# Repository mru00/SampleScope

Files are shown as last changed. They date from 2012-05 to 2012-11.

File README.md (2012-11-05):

SampleScope
===========

A cheap, simple, and fun-to-build diy USB oscilloscope

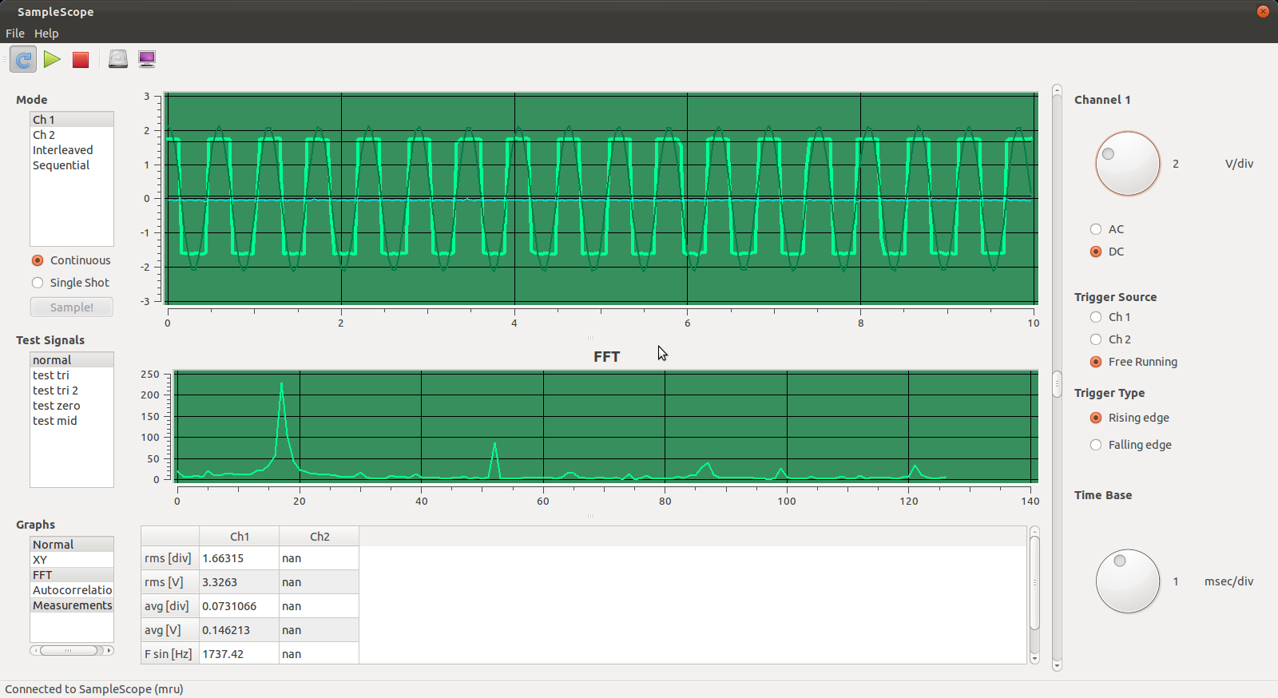
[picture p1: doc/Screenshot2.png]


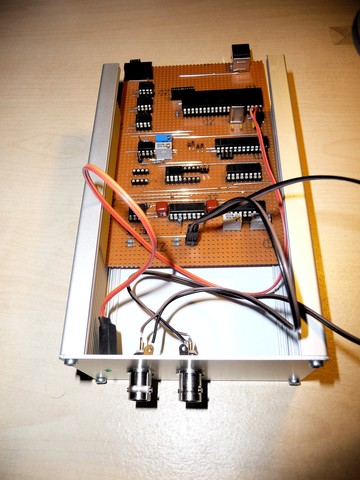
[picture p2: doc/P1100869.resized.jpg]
PCB


Schematics based on http://jonw0224.tripod.com/ppmscope.html

* USB oscilloscope
* two channels
* almost all parts can be sampled directly from the manufacturer
* almost no parts needed anyhow, some capacitors and resistors
* pcb is really simple an can be done on perfboard
* input range +- 12V
* bandwidth about 200kHz, 1MSPS
* 1024 samples 

Hardware
--------

* PIC18F4455
* USB 2.0 Full Speed HID device
* simple analog part
 * input limiting & buffering
 * optional DC removal
 * programmable gain amplifier (0.05, 0.1, 0.2, 0.5, 1, 2, 5, 10 V/div)
 * level shifter
 * ADC
 * no anti aliasing filter
* trigger system
 * can trigger on both channel 1, channel 2, or free running
 * can trigger on rising or falling edge
* time bases 'fastest' (~17u), 100u, 300u, 1m, 3m, 10m, 30m, 100m sec/div
* input selection
 * sample single channel, two channel interleaved or two channel sequential
* uses dc-dc converter (xp power IQ0515) to supply analog circuitry
* everything is powered from USB - no external supply required

* IC List
 * all parts can be sampled, at least as a student.
 * MAX114 as ADC
 * MAX532 as DAC: programmable gain amplifier and trigger voltage generation
 * MAX942 as trigger comparator
 * MAX4622 as AC/DC selector
 * MAX6225, MAX6241, MAX6250 as voltage references
 * TLE2082 as Op Amp
 * PIC18F4455 as brain
 
* PCB
 * as simple as it gets
 * analog parts are simple to wire
 * digital connections are "flying wires", verowire

Firmware
--------

Very simple firmware based on the Microchip Application Library USB example, 
most parts written in C, sampling routines written in ASM.

Frontend
--------

PC software written in C++ / Qt. OS independence by using libHIDAPI.
* Hardware emulation
* Plots
 * Normal
 * XY plot
 * FFT
 * autocorrelation
* Measurements
 * frequency
 * RMS and average voltage
* software emulation mode
 * emulates hardware, allows testing without the actual device

* development
 * uses HIDAPI https://github.com/signal11/hidapi
 * libqt4
 * libfftw3
 * libqwt6
 * libusb-1.0

To do
-----

* build better PGA (the current one is the main bottleneck in bandwidth)
* put more effort into PCB layout
 * i fixed some errors "on-line" without rerouting the pcb
* find cheaper DC-DC converter
* put some effort into graphical frontend
 * more measurements
 * more switches and customization
 * clean calibration ui, calibration wizards
* cleanup code a little bit, get build environment better (link with HIDAPI)
* platform independence (HIDAPI, libusb)
* anti aliasing filter (!!!)

Probably I won't do any of those items. ;)

License
-------
    SampleScope
    Copyright (C) 2012 mru

    This program is free software: you can redistribute it and/or modify
    it under the terms of the GNU General Public License as published by
    the Free Software Foundation, either version 3 of the License, or
    (at your option) any later version.

    This program is distributed in the hope that it will be useful,
    but WITHOUT ANY WARRANTY; without even the implied warranty of
    MERCHANTABILITY or FITNESS FOR A PARTICULAR PURPOSE.  See the
    GNU General Public License for more details.

    You should have received a copy of the GNU General Public License
    along with this program.  If not, see <http://www.gnu.org/licenses/>.

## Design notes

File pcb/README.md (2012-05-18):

pcb
===

contains the schematics & pcb layout.

see /doc/schematics.pdf and /doc/pcb.pdf for rendered versions, 
or check out kicad:

kicad schematic entry & pcb layout software.
http://iut-tice.ujf-grenoble.fr/kicad/

NB: the schematics and pcb layout are quite messy - i did not
draw them for the "end user" but rather as guide for me.

nevertheless, with some care, the device should be buildable.

analog
------

all analog paths (except some quick-fixes on my actual hardware) are routed
directly to fit on a perfboard. top and bottom layer are used, while
the top layer only has vertical connections.

digital
-------

all digital connections are simple point-to-point connections
with insolated wire (cf. http://en.wikipedia.org/wiki/Wiring_pencil)
_.

issues
------

* Analog bandwith is mostly limited by the PGA (MAX532) -> find a better solution
* Inputs are wired terribly, huge crosstalk if one channel is left unconnected -> change layout

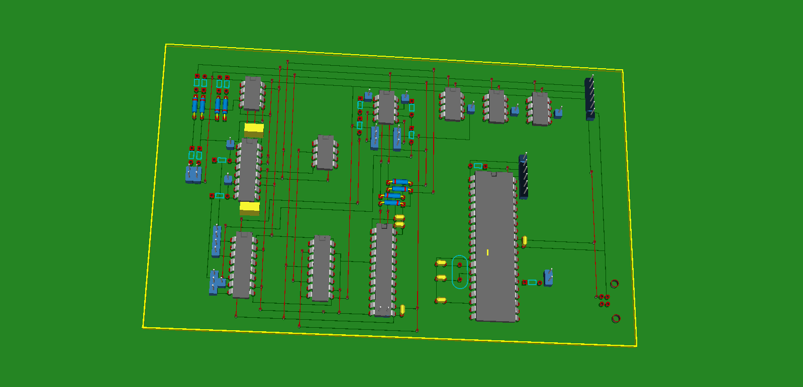
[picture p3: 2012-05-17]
doc/pcb_3d.png

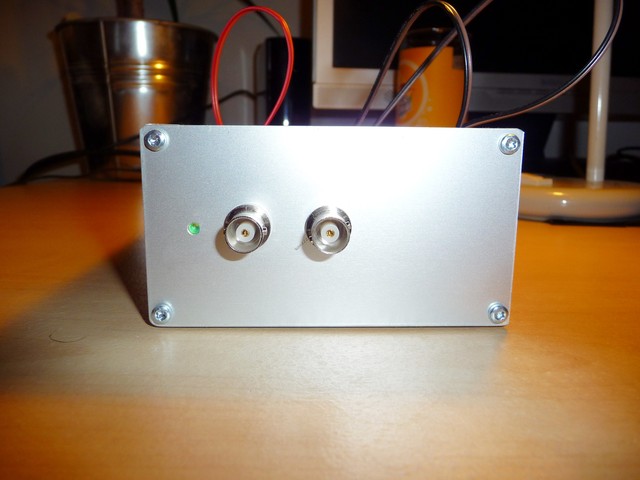
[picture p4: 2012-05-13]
doc/P1100871.resized.jpeg

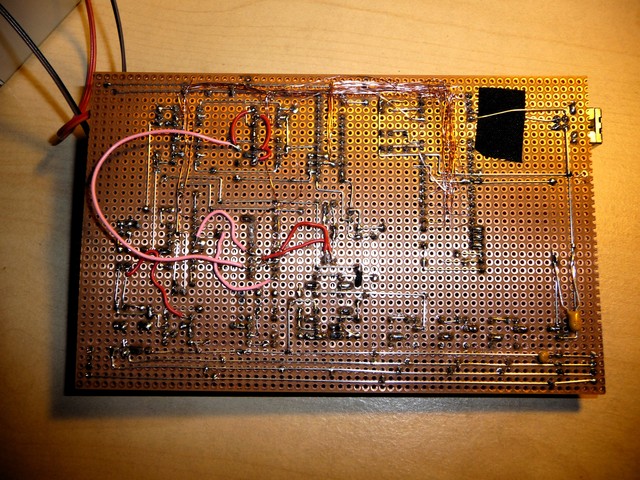
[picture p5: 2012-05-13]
doc/P1100872.resized.jpeg

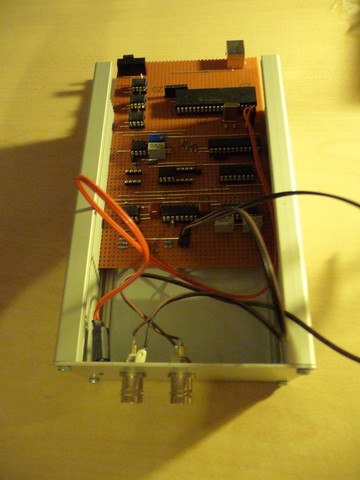
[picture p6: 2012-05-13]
doc/P1100868.resized.jpg

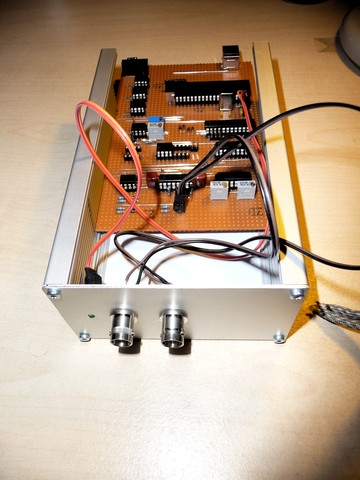
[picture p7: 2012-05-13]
doc/P1100870.resized.jpeg

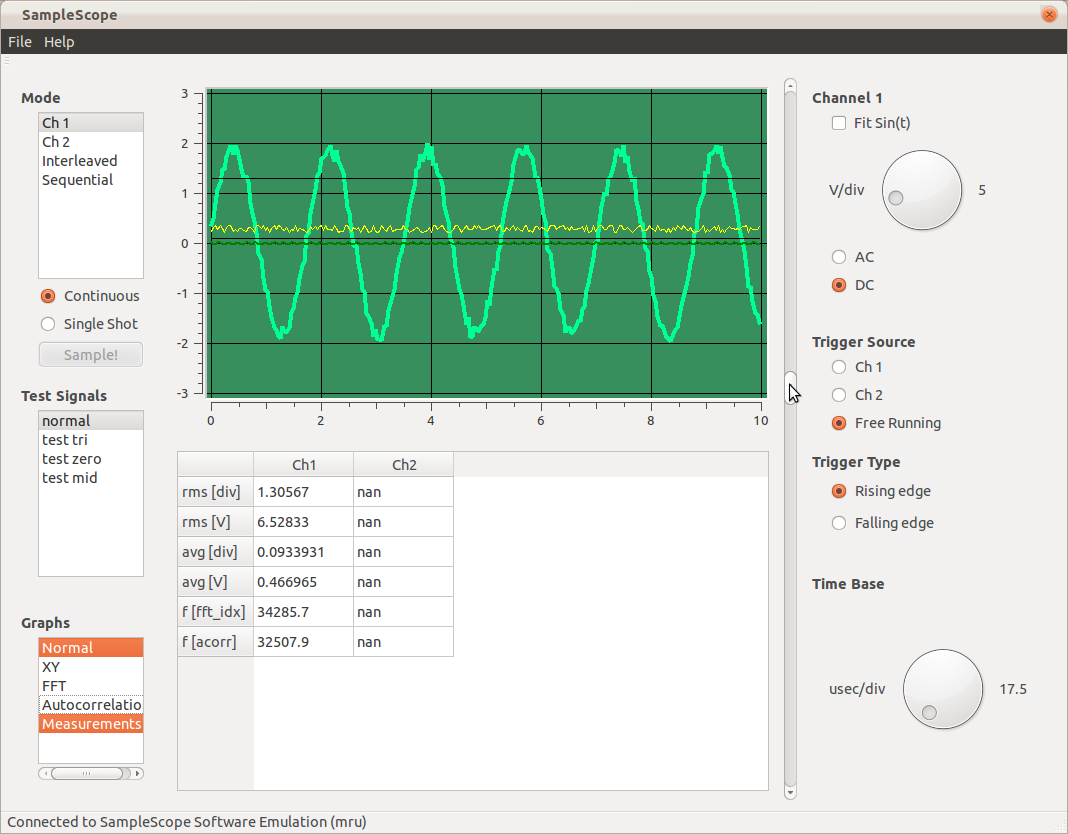
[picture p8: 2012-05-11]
doc/Screenshot1.png

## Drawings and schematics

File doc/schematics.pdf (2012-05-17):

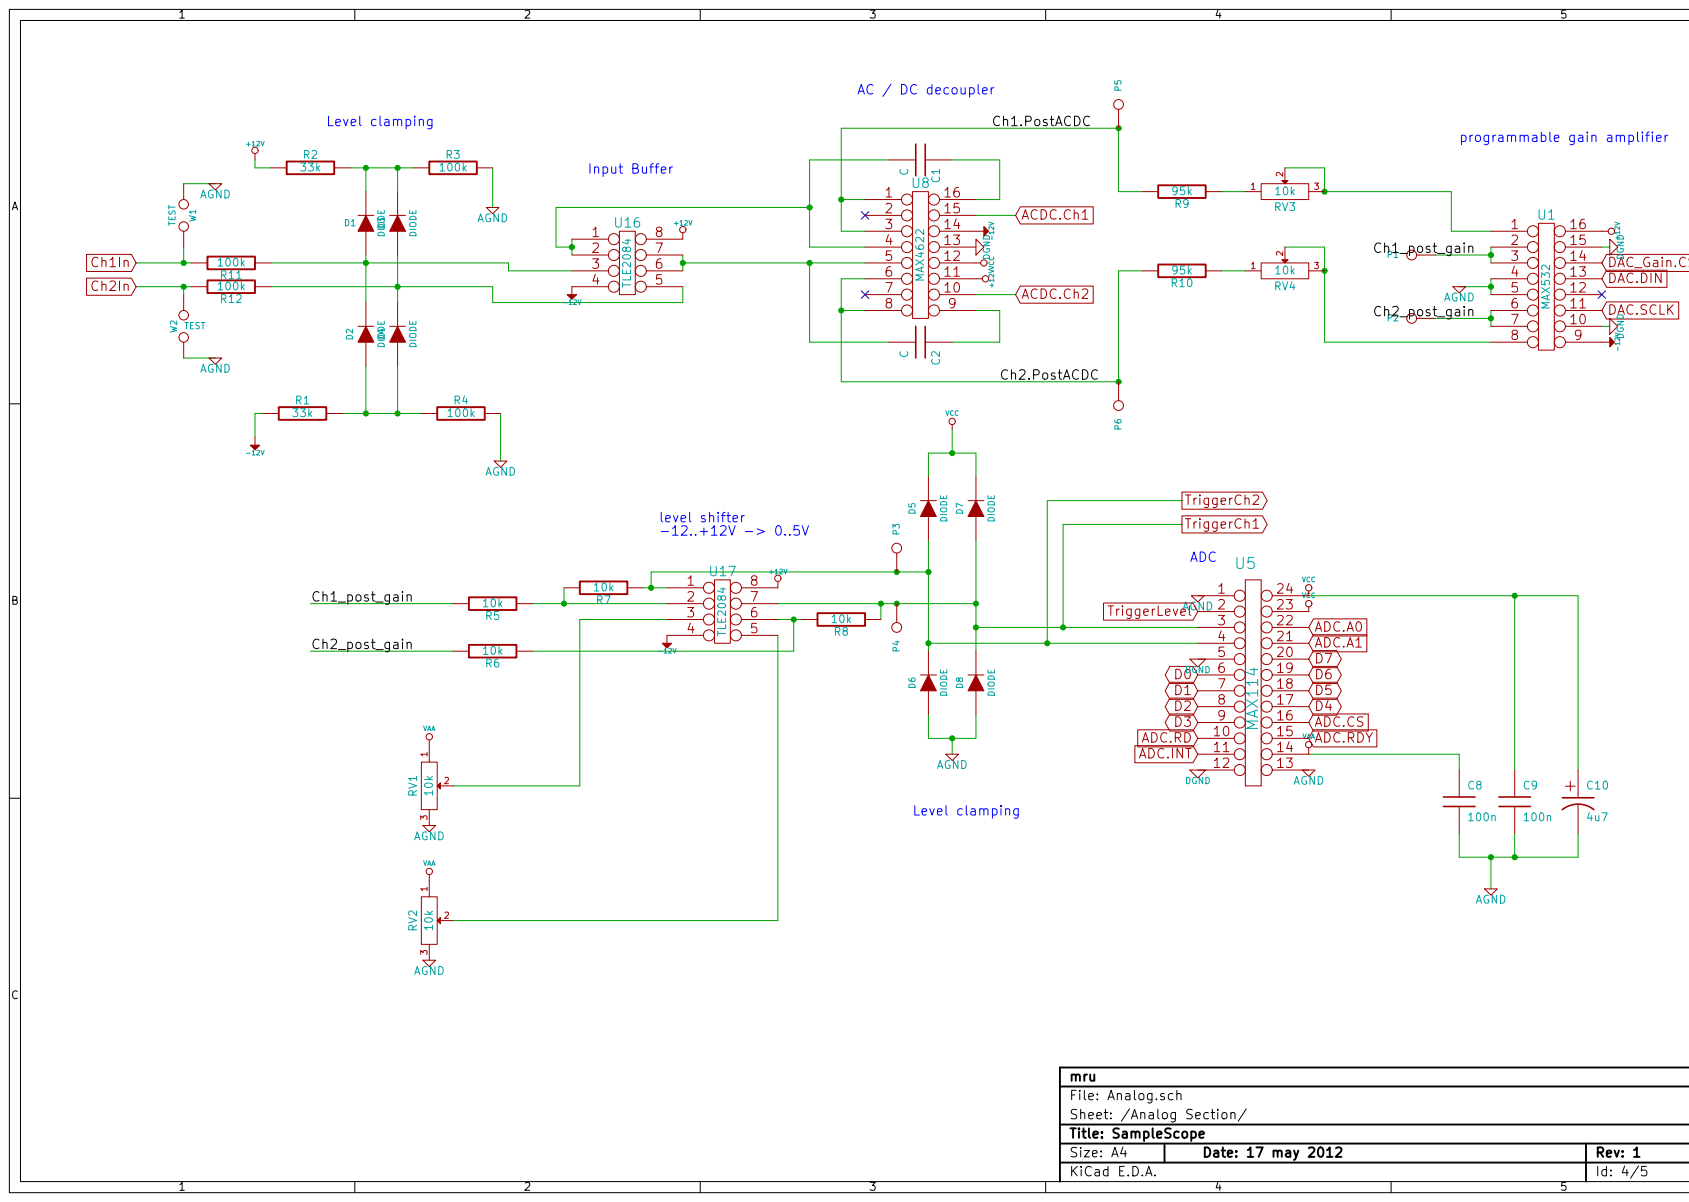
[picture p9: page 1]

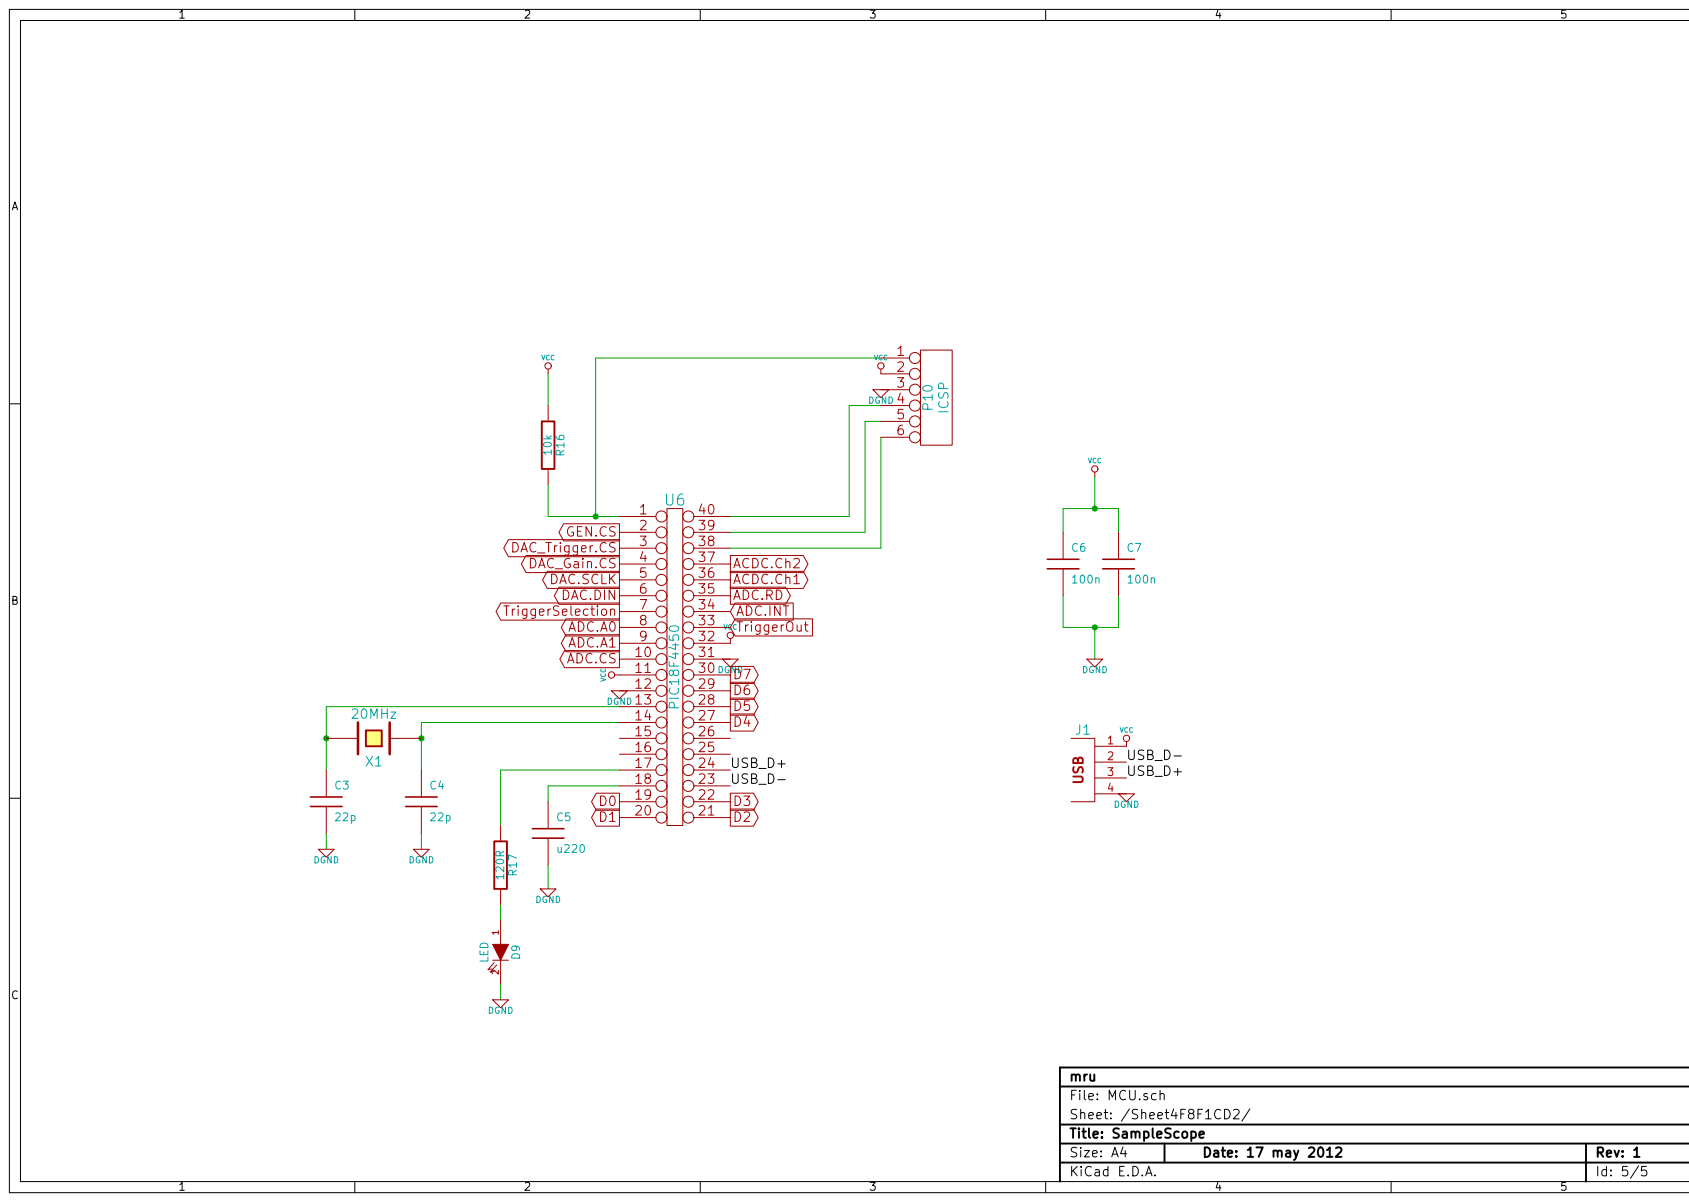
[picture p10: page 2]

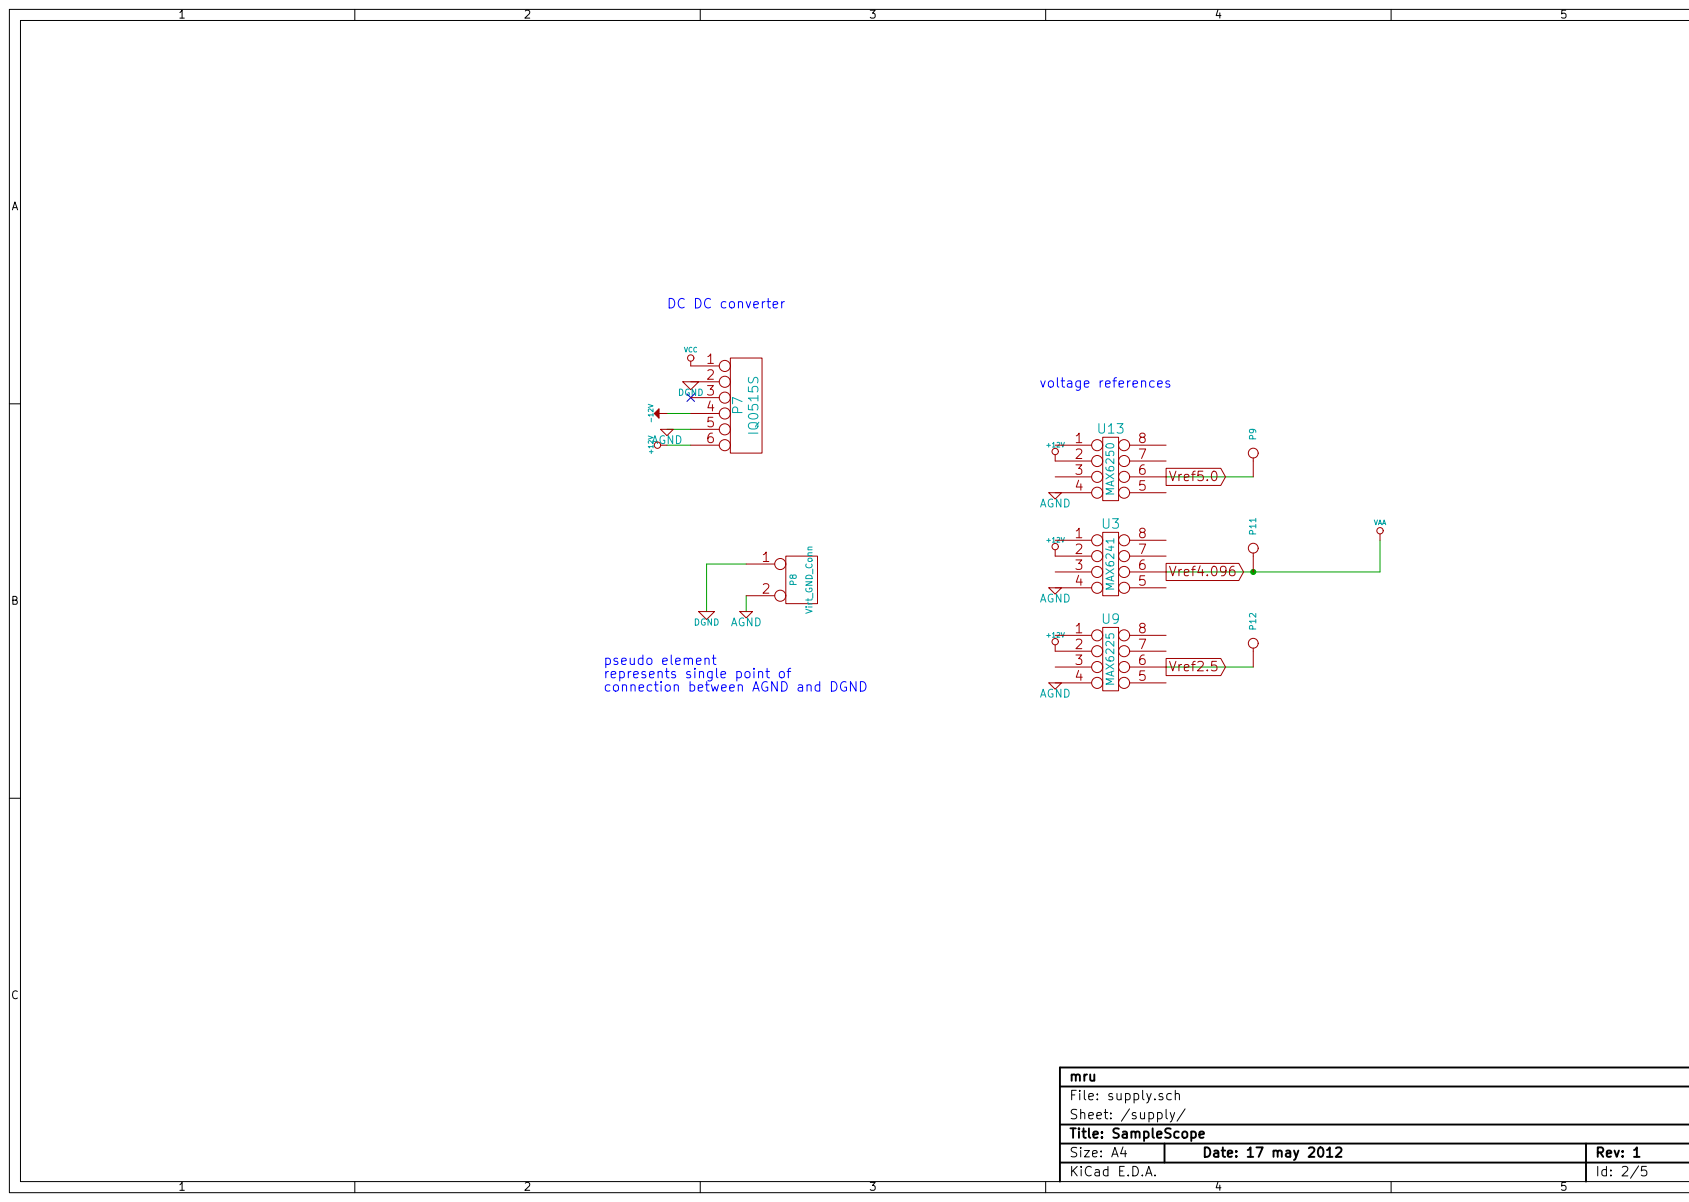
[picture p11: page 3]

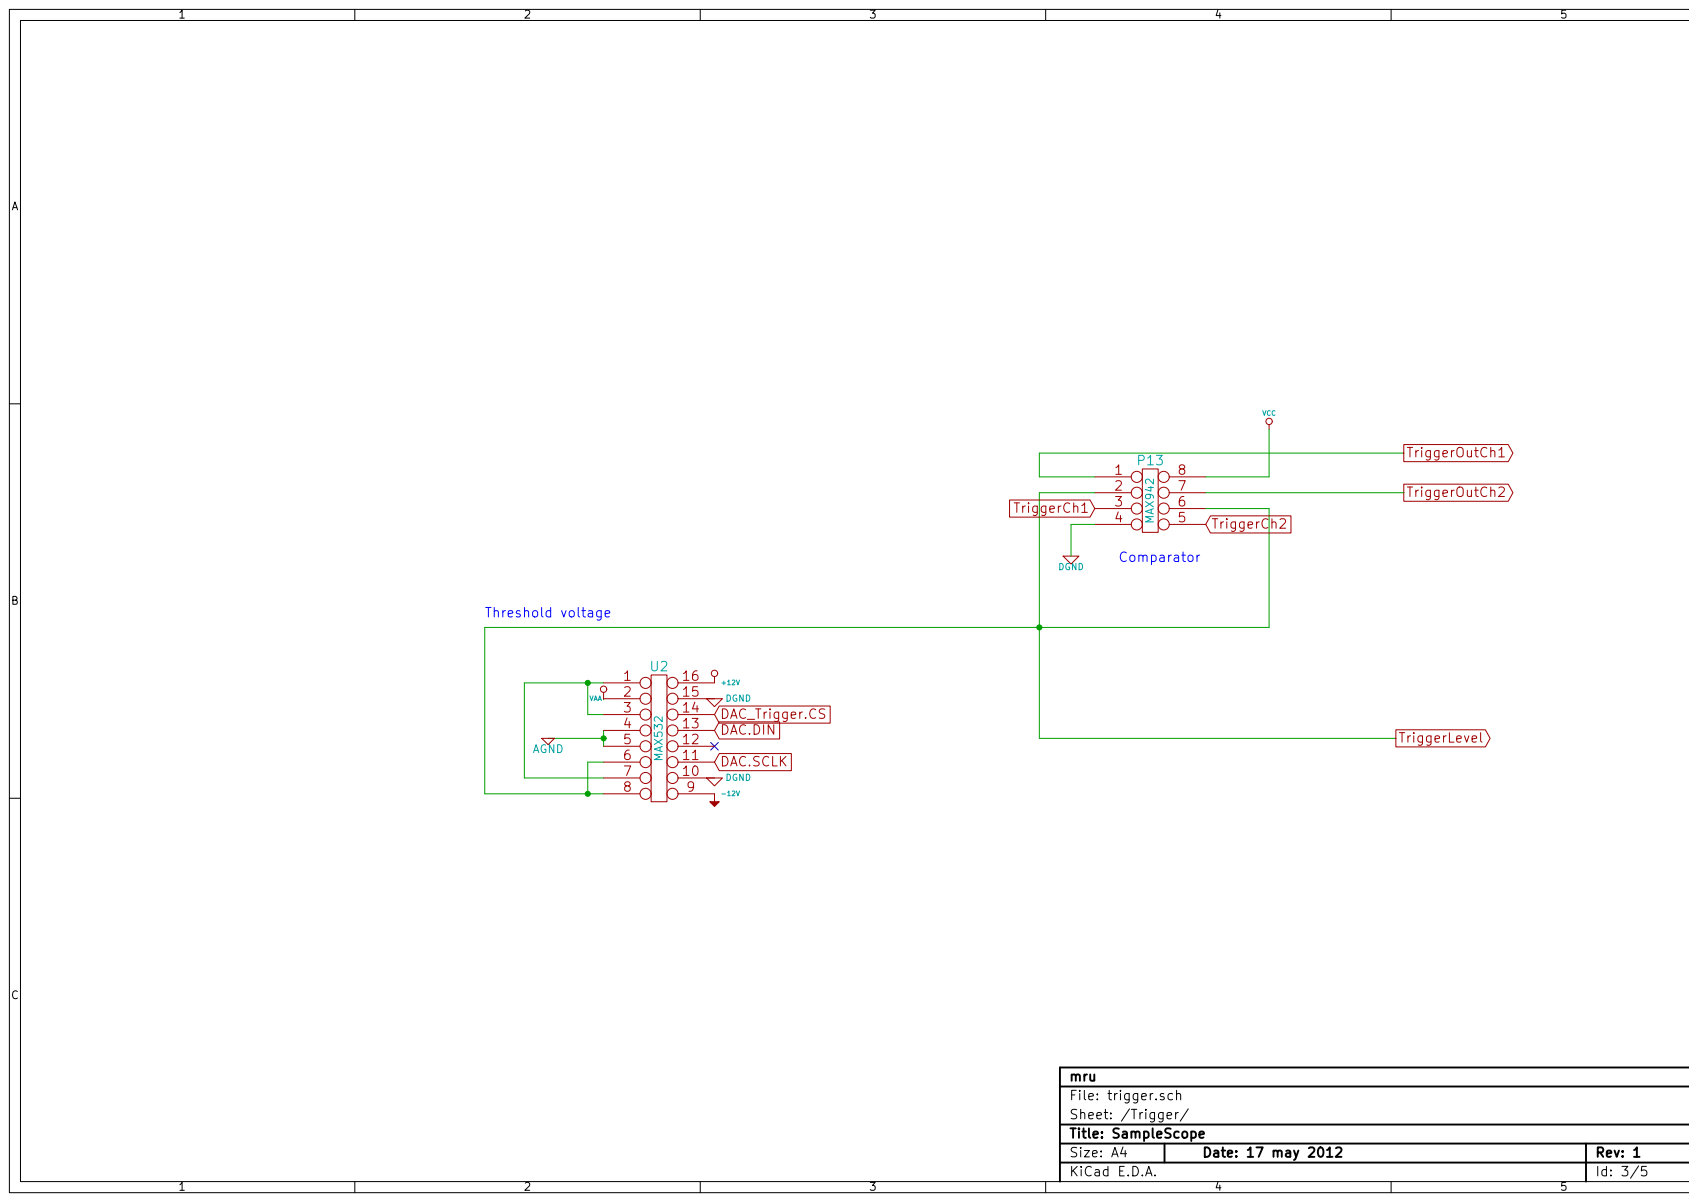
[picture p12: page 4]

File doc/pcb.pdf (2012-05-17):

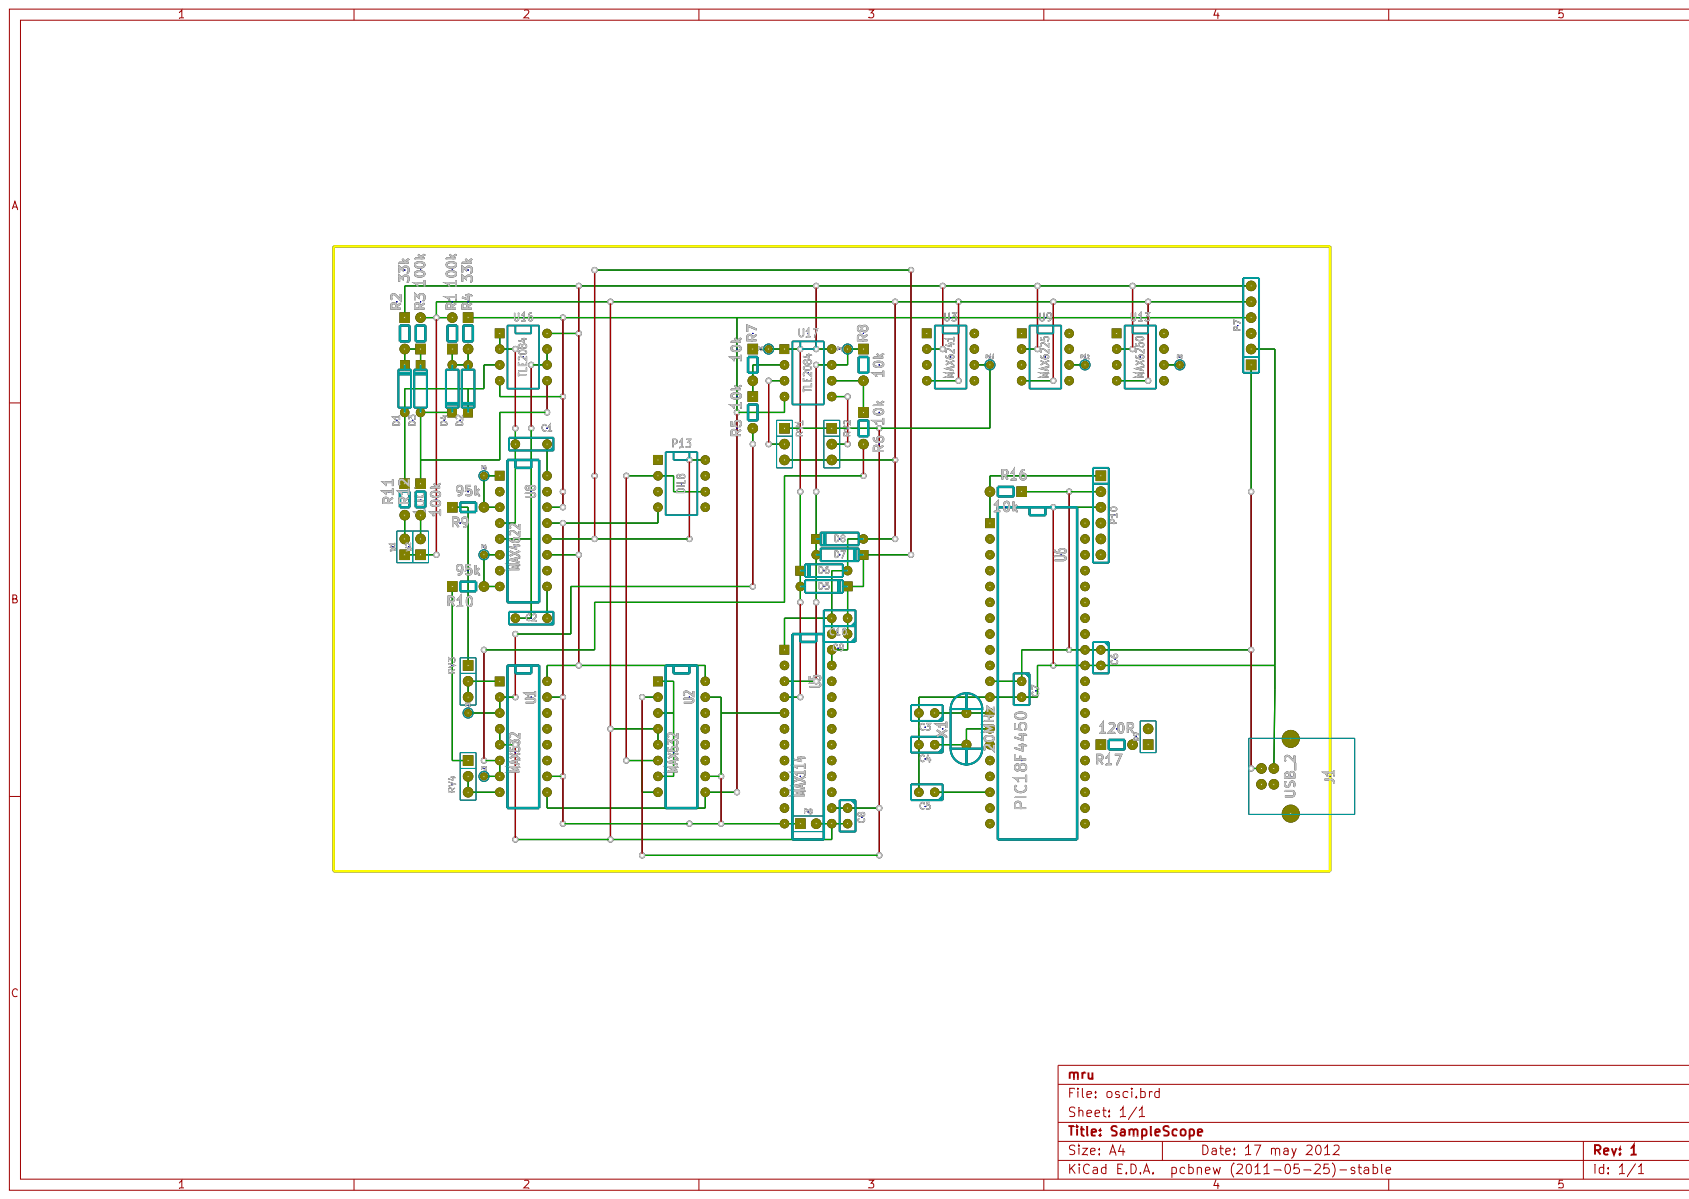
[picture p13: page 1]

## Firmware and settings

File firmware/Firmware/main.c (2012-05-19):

/********************************************************************
 FileName:     main.c
 Dependencies: See INCLUDES section
 Processor:		PIC18, PIC24, and PIC32 USB Microcontrollers
 Hardware:		This demo is natively intended to be used on Microchip USB demo
                                boards supported by the MCHPFSUSB stack.  See release notes for
                                support matrix.  This demo can be modified for use on other hardware
                                platforms.
 Complier:  	Microchip C18 (for PIC18), C30 (for PIC24), C32 (for PIC32)
 Company:		Microchip Technology, Inc.

 Software License Agreement:

 The software supplied herewith by Microchip Technology Incorporated
 (the �Company�) for its PIC� Microcontroller is intended and
 supplied to you, the Company�s customer, for use solely and
 exclusively on Microchip PIC Microcontroller products. The
 software is owned by the Company and/or its supplier, and is
 protected under applicable copyright laws. All rights are reserved.
 Any use in violation of the foregoing restrictions may subject the
 user to criminal sanctions under applicable laws, as well as to
 civil liability for the breach of the terms and conditions of this
 license.

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
 ********************************************************************
 File Description:

 Change History:
  Rev   Description
  ----  -----------------------------------------
  1.0   Initial release
  2.1   Updated for simplicity and to use common
                     coding style
  2.7b  Improvements to USBCBSendResume(), to make it easier to use.
 ********************************************************************/


/** INCLUDES *******************************************************/
#include "./USB/usb.h"
#include "./HardwareProfile.h"
#include "./USB/usb_function_hid.h"
#include <timers.h>
#include <compare.h>


#include "config_bits.h"


/** VARIABLES ******************************************************/
#pragma udata USB_VARIABLES=0x480
unsigned char ReceivedData[64];
unsigned char ToSendDataBuffer[64];

#pragma idata

USB_HANDLE USBOutHandle = 0;
USB_HANDLE USBInHandle = 0;

/** PRIVATE PROTOTYPES *********************************************/
static void InitializeSystem(void);
extern void ProcessIO(void);
extern void UserInit(void);

//void USBCBSendResume(void);
static void BlinkUSBStatus(void);
extern void resetState(void);

/** DECLARATIONS ***************************************************/
#pragma code

/********************************************************************
 * Function:        void main(void)
 *
 * PreCondition:    None
 *
 * Input:           None
 *
 * Output:          None
 *
 * Side Effects:    None
 *
 * Overview:        Main program entry point.
 *
 * Note:            None
 *******************************************************************/
void main(void) {
    InitializeSystem();

#if defined(USB_INTERRUPT)
    USBDeviceAttach();
#endif

    while (1) {
#if defined(USB_POLLING)
        // Check bus status and service USB interrupts.
        USBDeviceTasks(); // Interrupt or polling method.  If using polling, must call
        // this function periodically.  This function will take care
        // of processing and responding to SETUP transactions
        // (such as during the enumeration process when you first
        // plug in).  USB hosts require that USB devices should accept
        // and process SETUP packets in a timely fashion.  Therefore,
        // when using polling, this function should be called
        // regularly (such as once every 1.8ms or faster** [see
        // inline code comments in usb_device.c for explanation when
        // "or faster" applies])  In most cases, the USBDeviceTasks()
        // function does not take very long to execute (ex: <100
        // instruction cycles) before it returns.
#endif


        // Application-specific tasks.
        // Application related code may be added here, or in the ProcessIO() function.
        ProcessIO();
    }//end while
}//end main

/********************************************************************
 * Function:        static void InitializeSystem(void)
 *
 * Overview:        InitializeSystem is a centralize initialization
 *                  routine. All required USB initialization routines
 *                  are called from here.
 *
 *                  User application initialization routine should
 *                  also be called from here.                  
 *
 * Note:            None
 *******************************************************************/
static void InitializeSystem(void) {
    ADCON1 |= 0x0F; // Default all pins to digital

#if defined(PIC18F87J50_PIM) || defined(PIC18F46J50_PIM) || defined(PIC18F_STARTER_KIT_1) || defined(PIC18F47J53_PIM)
    //On the PIC18F87J50 Family of USB microcontrollers, the PLL will not power up and be enabled
    //by default, even if a PLL enabled oscillator configuration is selected (such as HS+PLL).
    //This allows the device to power up at a lower initial operating frequency, which can be
    //advantageous when powered from a source which is not gauranteed to be adequate for 48MHz
    //operation.  On these devices, user firmware needs to manually set the OSCTUNE<PLLEN> bit to
    //power up the PLL.
    {
        unsigned int pll_startup_counter = 600;
        OSCTUNEbits.PLLEN = 1; //Enable the PLL and wait 2+ms until the PLL locks before enabling USB module
        while (pll_startup_counter--);
    }
    //Device switches over automatically to PLL output after PLL is locked and ready.
#endif

#if defined(PIC18F87J50_PIM)
    //Configure all I/O pins to use digital input buffers.  The PIC18F87J50 Family devices
    //use the ANCONx registers to control this, which is different from other devices which
    //use the ADCON1 register for this purpose.
    WDTCONbits.ADSHR = 1; // Select alternate SFR location to access ANCONx registers
    ANCON0 = 0xFF; // Default all pins to digital
    ANCON1 = 0xFF; // Default all pins to digital
    WDTCONbits.ADSHR = 0; // Select normal SFR locations
#endif


    //	The USB specifications require that USB peripheral devices must never source
    //	current onto the Vbus pin.  Additionally, USB peripherals should not source
    //	current on D+ or D- when the host/hub is not actively powering the Vbus line.
    //	When designing a self powered (as opposed to bus powered) USB peripheral
    //	device, the firmware should make sure not to turn on the USB module and D+
    //	or D- pull up resistor unless Vbus is actively powered.  Therefore, the
    //	firmware needs some means to detect when Vbus is being powered by the host.
    //	A 5V tolerant I/O pin can be connected to Vbus (through a resistor), and
    // 	can be used to detect when Vbus is high (host actively powering), or low
    //	(host is shut down or otherwise not supplying power).  The USB firmware
    // 	can then periodically poll this I/O pin to know when it is okay to turn on
    //	the USB module/D+/D- pull up resistor.  When designing a purely bus powered
    //	peripheral device, it is not possible to source current on D+ or D- when the
    //	host is not actively providing power on Vbus. Therefore, implementing this
    //	bus sense feature is optional.  This firmware can be made to use this bus
    //	sense feature by making sure "USE_USB_BUS_SENSE_IO" has been defined in the
    //	HardwareProfile.h file.
#if defined(USE_USB_BUS_SENSE_IO)
    tris_usb_bus_sense = INPUT_PIN; // See HardwareProfile.h
#endif

    //	If the host PC sends a GetStatus (device) request, the firmware must respond
    //	and let the host know if the USB peripheral device is currently bus powered
    //	or self powered.  See chapter 9 in the official USB specifications for details
    //	regarding this request.  If the peripheral device is capable of being both
    //	self and bus powered, it should not return a hard coded value for this request.
    //	Instead, firmware should check if it is currently self or bus powered, and
    //	respond accordingly.  If the hardware has been configured like demonstrated
    //	on the PICDEM FS USB Demo Board, an I/O pin can be polled to determine the
    //	currently selected power source.  On the PICDEM FS USB Demo Board, "RA2"
    //	is used for	this purpose.  If using this feature, make sure "USE_SELF_POWER_SENSE_IO"
    //	has been defined in HardwareProfile.h, and that an appropriate I/O pin has been mapped
    //	to it in HardwareProfile.h.
#if defined(USE_SELF_POWER_SENSE_IO)
    tris_self_power = INPUT_PIN; // See HardwareProfile.h
#endif

    UserInit();

    USBDeviceInit(); //usb_device.c.  Initializes USB module SFRs and firmware
    //variables to known states.
}//end InitializeSystem


/********************************************************************
 * Function:        void BlinkUSBStatus(void)
 *
 * PreCondition:    None
 *
 * Input:           None
 *
 * Output:          None
 *
 * Side Effects:    None
 *
 * Overview:        BlinkUSBStatus turns on and off LEDs 
 *                  corresponding to the USB device state.
 *
 * Note:            mLED macros can be found in HardwareProfile.h
 *                  USBDeviceState is declared and updated in
 *                  usb_device.c.
 *******************************************************************/
void BlinkUSBStatus(void) {
    // No need to clear UIRbits.SOFIF to 0 here.
    // Callback caller is already doing that.

    if (USBSuspendControl == 1) {
    } else {
        if (USBDeviceState == DETACHED_STATE) {
        } else if (USBDeviceState == ATTACHED_STATE) {
        } else if (USBDeviceState == POWERED_STATE) {
        } else if (USBDeviceState == DEFAULT_STATE) {
        } else if (USBDeviceState == ADDRESS_STATE) {
        } else if (USBDeviceState == CONFIGURED_STATE) {
        }
    }

}//end BlinkUSBStatus

/*******************************************************************
 * Function:        void USBCBInitEP(void)
 *
 * PreCondition:    None
 *
 * Input:           None
 *
 * Output:          None
 *
 * Side Effects:    None
 *
 * Overview:        This function is called when the device becomes
 *                  initialized, which occurs after the host sends a
 * 					SET_CONFIGURATION (wValue not = 0) request.  This
 *					callback function should initialize the endpoints
 *					for the device's usage according to the current
 *					configuration.
 *
 * Note:            None
 *******************************************************************/
void USBCBInitEP(void) {
    //enable the HID endpoint
    USBEnableEndpoint(HID_EP, USB_IN_ENABLED | USB_OUT_ENABLED | USB_HANDSHAKE_ENABLED | USB_DISALLOW_SETUP);
    //Re-arm the OUT endpoint for the next packet
    USBOutHandle = HIDRxPacket(HID_EP, (BYTE*) & ReceivedData, 64);
    resetState();
}

/*******************************************************************
 * Function:        void USBCBErrorHandler(void)
 *
 * PreCondition:    None
 *
 * Input:           None
 *
 * Output:          None
 *
 * Side Effects:    None
 *
 * Overview:        The purpose of this callback is mainly for
 *                  debugging during development. Check UEIR to see
 *                  which error causes the interrupt.
 *
 * Note:            None
 *******************************************************************/
void USBCBErrorHandler(void) {
    // No need to clear UEIR to 0 here.
    // Callback caller is already doing that.

    // Typically, user firmware does not need to do anything special
    // if a USB error occurs.  For example, if the host sends an OUT
    // packet to your device, but the packet gets corrupted (ex:
    // because of a bad connection, or the user unplugs the
    // USB cable during the transmission) this will typically set
    // one or more USB error interrupt flags.  Nothing specific
    // needs to be done however, since the SIE will automatically
    // send a "NAK" packet to the host.  In response to this, the
    // host will normally retry to send the packet again, and no
    // data loss occurs.  The system will typically recover
    // automatically, without the need for application firmware
    // intervention.

    resetState();
    // Nevertheless, this callback function is provided, such as
    // for debugging purposes.
}

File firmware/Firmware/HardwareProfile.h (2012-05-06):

/********************************************************************
 FileName:     	HardwareProfile - PICDEM FSUSB.h
 Dependencies:  See INCLUDES section
 Processor:     PIC18 USB Microcontrollers
 Hardware:      PICDEM FSUSB
 Compiler:      Microchip C18
 Company:       Microchip Technology, Inc.

 Software License Agreement:

 The software supplied herewith by Microchip Technology Incorporated
 (the �Company�) for its PIC� Microcontroller is intended and
 supplied to you, the Company�s customer, for use solely and
 exclusively on Microchip PIC Microcontroller products. The
 software is owned by the Company and/or its supplier, and is
 protected under applicable copyright laws. All rights are reserved.
 Any use in violation of the foregoing restrictions may subject the
 user to criminal sanctions under applicable laws, as well as to
 civil liability for the breach of the terms and conditions of this
 license.

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
********************************************************************
 File Description:

 Change History:
  Rev   Date         Description
  1.0   11/19/2004   Initial release
  2.1   02/26/2007   Updated for simplicity and to use common
                     coding style
  2.3   09/15/2008   Broke out each hardware platform into its own
                     "HardwareProfile - xxx.h" file
********************************************************************/

#ifndef HARDWARE_PROFILE_mypic_H
#define HARDWARE_PROFILE_mypic_H

    /*******************************************************************/
    /******** USB stack hardware selection options *********************/
    /*******************************************************************/
    //This section is the set of definitions required by the MCHPFSUSB
    //  framework.  These definitions tell the firmware what mode it is
    //  running in, and where it can find the results to some information
    //  that the stack needs.
    //These definitions are required by every application developed with
    //  this revision of the MCHPFSUSB framework.  Please review each
    //  option carefully and determine which options are desired/required
    //  for your application.

    //The PICDEM FS USB Demo Board platform supports the USE_SELF_POWER_SENSE_IO
    //and USE_USB_BUS_SENSE_IO features.  Uncomment the below line(s) if
    //it is desireable to use one or both of the features.
    //#define USE_SELF_POWER_SENSE_IO
    #define tris_self_power     TRISAbits.TRISA2    // Input
    #if defined(USE_SELF_POWER_SENSE_IO)
    #define self_power          PORTAbits.RA2
    #else
    #define self_power          1
    #endif

    //#define USE_USB_BUS_SENSE_IO
    #define tris_usb_bus_sense  TRISAbits.TRISA1    // Input
    #if defined(USE_USB_BUS_SENSE_IO)
    #define USB_BUS_SENSE       PORTAbits.RA1
    #else
    #define USB_BUS_SENSE       1
    #endif


    //Uncomment the following line to make the output HEX of this  
    //  project work with the MCHPUSB Bootloader    
    //#define PROGRAMMABLE_WITH_USB_MCHPUSB_BOOTLOADER
	
    //Uncomment the following line to make the output HEX of this 
    //  project work with the HID Bootloader
    #define PROGRAMMABLE_WITH_USB_HID_BOOTLOADER

    /*******************************************************************/
    /*******************************************************************/
    /*******************************************************************/
    /******** Application specific definitions *************************/
    /*******************************************************************/
    /*******************************************************************/
    /*******************************************************************/

    /** Board definition ***********************************************/
    //These defintions will tell the main() function which board is
    //  currently selected.  This will allow the application to add
    //  the correct configuration bits as wells use the correct
    //  initialization functions for the board.  These defitions are only
    //  required in the stack provided demos.  They are not required in
    //  final application design.
    #define DEMO_BOARD mypic_USB
    #define mypic_USB
    #define CLOCK_FREQ 48000000


    /** LED ************************************************************/


#define I_TriggerCh1 PORTBbits.RB0
#define I_TriggerCh2 PORTAbits.RA5

#define I_ADC_INT  PORTBbits.RB1
#define O_ADC_RD   LATBbits.LATB2
#define O_ADC_A0   LATEbits.LATE0
#define O_ADC_A1   LATEbits.LATE1
#define O_ADC_CS   LATEbits.LATE2
#define I_ADC_PORT PORTD

#define O_DAC_Trigger_CS LATAbits.LATA1
#define O_DAC_Gain_CS    LATAbits.LATA2
#define O_DAC_SCLK       LATAbits.LATA3
#define O_DAC_DIN        LATAbits.LATA4
#define O_LED LATCbits.LATC2

#define O_ACDC_Ch1 LATBbits.LATB3
#define O_ACDC_Ch2 LATBbits.LATB4

    /** I/O pin definitions ********************************************/
    #define INPUT_PIN 1
    #define OUTPUT_PIN 0
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

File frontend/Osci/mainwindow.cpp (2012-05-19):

/*

SampleScope: A humble USB oscilloscope
Copyright (C) 2012 mru

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
You should have received a copy of the GNU General Public License
along with this program.  If not, see <http://www.gnu.org/licenses/>.
*/


#include <iostream>
#include <QFileDialog>
#include <QMessageBox>

#include "mainwindow.h"
#include "ui_mainwindow.h"

#include "aboutdialog.h"

using namespace std;

MainWindow::MainWindow(QWidget *parent)
    : QMainWindow(parent)
    , ui(new Ui::MainWindow)
    , device()
    , model(this)
    , currentMode(ModeControl::Mode_Ch1)
    , calibDlg(&device, this)
{
    ui->setupUi(this);


    ui->channelControlCh1->setChannel(DeviceConstants::ADC_ch1);
    ui->channelControlCh2->setChannel(DeviceConstants::ADC_ch2);
    ui->widgetMeasurements->setModel(&model);

    QMap<QAction*, QStyle::StandardPixmap> buttonIcons;
    QStyle* s = QApplication::style();
    buttonIcons[ui->actionConnect] = QStyle::SP_MediaPlay;
    buttonIcons[ui->actionDisconnect] = QStyle::SP_MediaStop;
    buttonIcons[ui->actionAuto_connect] = QStyle::SP_BrowserReload;
    buttonIcons[ui->actionUse_real_hardware] = QStyle::SP_DriveHDIcon;
    buttonIcons[ui->actionUse_software_emulation] = QStyle::SP_ComputerIcon;

    QMapIterator<QAction*, QStyle::StandardPixmap> i(buttonIcons);
    while (i.hasNext()) {
        i.next();
        i.key()->setIcon(s->standardIcon(i.value()));
    }

    connect(&updateTimer, SIGNAL(timeout()), &device, SLOT(refresh()));
    connect(&sampleTimer, SIGNAL(timeout()), this, SLOT(sample()));
    connect(&device, SIGNAL(connected(QString, QString)), this, SLOT(deviceConnected(QString, QString)));
    connect(&device, SIGNAL(disconnected()), this, SLOT(deviceDisconnected()));
    connect(&device, SIGNAL(fatal(QString)), this, SLOT(fatal(QString)));

    connect(ui->channelControlCh1, SIGNAL(vdivSelected(DeviceConstants::VdivValues_t)), this, SLOT(VdivCh1Adjusted(DeviceConstants::VdivValues_t)));
    connect(ui->channelControlCh1, SIGNAL(vdivSelected(DeviceConstants::VdivValues_t)), &meas, SLOT(setVdiv_Ch1(DeviceConstants::VdivValues_t)));
    connect(ui->channelControlCh1, SIGNAL(acdcSelected(DeviceConstants::ACDC_t)), this, SLOT(ACDCCh1Adjusted(DeviceConstants::ACDC_t)));

    connect(ui->channelControlCh2, SIGNAL(vdivSelected(DeviceConstants::VdivValues_t)), this, SLOT(VdivCh2Adjusted(DeviceConstants::VdivValues_t)));
    connect(ui->channelControlCh2, SIGNAL(vdivSelected(DeviceConstants::VdivValues_t)), &meas, SLOT(setVdiv_Ch2(DeviceConstants::VdivValues_t)));
    connect(ui->channelControlCh2, SIGNAL(acdcSelected(DeviceConstants::ACDC_t)), this, SLOT(ACDCCh2Adjusted(DeviceConstants::ACDC_t)));

    connect(ui->triggerControl, SIGNAL(triggerSourceSelected(DeviceConstants::TriggerSource_t)), this, SLOT(triggerSourceSelected(DeviceConstants::TriggerSource_t)));
    connect(ui->triggerControl, SIGNAL(triggerModeSelected(DeviceConstants::TriggerMode_t)), this, SLOT(triggerModeSelected(DeviceConstants::TriggerMode_t)));

    connect(ui->dialTriggerLevel, SIGNAL(valueChanged(int)), this, SLOT(TriggerLevelAdjusted(int)));
    connect(ui->timeControl, SIGNAL(TdivChanged(DeviceConstants::TdivValues_t)), this, SLOT(TdivAdjusted(DeviceConstants::TdivValues_t)));
    connect(ui->timeControl, SIGNAL(TdivChanged(DeviceConstants::TdivValues_t)), &meas, SLOT(setTdiv(DeviceConstants::TdivValues_t)));

    connect(ui->actionExport_Data, SIGNAL(triggered()), this, SLOT(exportData()));
    connect(ui->modeControl, SIGNAL(modeSelected(ModeControl::Modes_t)), this, SLOT(modeSelectionChanged(ModeControl::Modes_t)));
    connect(ui->modeControl, SIGNAL(modeSelected(ModeControl::Modes_t)), ui->graphNorm, SLOT(modeSelectionChanged(ModeControl::Modes_t)));
    connect(ui->modeControl, SIGNAL(modeSelected(ModeControl::Modes_t)), ui->graphXY, SLOT(modeSelectionChanged(ModeControl::Modes_t)));
    connect(ui->modeControl, SIGNAL(modeSelected(ModeControl::Modes_t)), ui->graphFFT, SLOT(modeSelectionChanged(ModeControl::Modes_t)));
    connect(ui->modeControl, SIGNAL(modeSelected(ModeControl::Modes_t)), ui->graphAutoCorr, SLOT(modeSelectionChanged(ModeControl::Modes_t)));
    connect(ui->modeControl, SIGNAL(updateSelected(ModeControl::Update_t)), this, SLOT(updateSelectionChanged(ModeControl::Update_t)));
    connect(ui->modeControl, SIGNAL(singleShot()), this, SLOT(singleShot()));
    connect(ui->modeControl, SIGNAL(testSignalSelected(DeviceConstants::TestSignal_t)), this, SLOT(TestSignalSelectionChanged(DeviceConstants::TestSignal_t)));

    connect(ui->graphControl, SIGNAL(graphSelected(QMap<GraphControl::Graphs_t,bool>)), this, SLOT(graphSelectionChanged(QMap<GraphControl::Graphs_t,bool>)));
    connect(ui->actionCalibration_Dialog, SIGNAL(triggered()), &calibDlg, SLOT(show()));

    statusBar()->showMessage("Searching for device. Tip: try software emulation.");
    centralWidget()->setEnabled(false);
    updateTimer.start(2500);
    sampleTimer.setInterval(500);

//    QSqlDatabase
}

MainWindow::~MainWindow()
{
    delete ui;
}

void MainWindow::closeEvent(QCloseEvent *) {
    device.disConnect();
    calibDlg.close();
}

void MainWindow::TestSignalSelectionChanged(DeviceConstants::TestSignal_t dummy) {
    device.setTestSignal(dummy);
}

void MainWindow::modeSelectionChanged(ModeControl::Modes_t mode) {
    currentMode = mode;

    switch(mode) {
    case ModeControl::Mode_Ch1:
        ui->channelControlCh1->setVisible(true);
        ui->channelControlCh2->setVisible(false);
        break;
    case ModeControl::Mode_Ch2:
        ui->channelControlCh1->setVisible(false);
        ui->channelControlCh2->setVisible(true);
        break;
    case ModeControl::Mode_Interleaved:
        ui->channelControlCh1->setVisible(true);
        ui->channelControlCh2->setVisible(true);
        break;
    case ModeControl::Mode_Sequential:
        ui->channelControlCh1->setVisible(true);
        ui->channelControlCh2->setVisible(true);
        break;
    }
}


void MainWindow::updateSelectionChanged(ModeControl::Update_t update) {
    switch (update) {
    case ModeControl::Update_Continuous:
        sampleTimer.start();
        break;
    case ModeControl::Update_Single:
        sampleTimer.stop();
        break;
    }
}

void MainWindow::singleShot() {
    sample();
}

void MainWindow::graphSelectionChanged(QMap<GraphControl::Graphs_t,bool> enabled) {

    ui->graphFFT->setVisible(enabled[GraphControl::Graph_FFT]);
    ui->graphNorm->setVisible(enabled[GraphControl::Graph_Normal]);
    ui->graphXY->setVisible(enabled[GraphControl::Graph_XY]);
    ui->graphAutoCorr->setVisible(enabled[GraphControl::Graph_AutoCorr]);
    ui->widgetMeasurements->setVisible(enabled[GraphControl::Graph_Measurements]);
}

void MainWindow::triggerSourceSelected(DeviceConstants::TriggerSource_t triggerSource) {
    device.selectTriggerSource(triggerSource);
    //curveTriggerLevel->setAxes(QwtPlot::xBottom, (triggerSource == Device::Trigger_Ch1) ? QwtPlot::yLeft : QwtPlot::yRight);
}
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

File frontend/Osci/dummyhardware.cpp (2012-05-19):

/*

SampleScope: A humble USB oscilloscope
Copyright (C) 2012 mru

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
You should have received a copy of the GNU General Public License
along with this program.  If not, see <http://www.gnu.org/licenses/>.
*/


#include "dummyhardware.h"
#include <cstdlib>
#include <cmath>




DummyHardware::DummyHardware(QObject *parent) :
    AbstractHardware(parent)
  , state(State_Closed)
{
}


void DummyHardware::open() {
    Q_ASSERT(!isOpen());
    state = State_Init;
}

void DummyHardware::close() {
    //Q_ASSERT(isOpen());
    state = State_Closed;
}


static void make_noise(unsigned char* target, int count, int level) {

    for (int i = 0; i < count; i ++ ) {
        target[i] = target[i] + ( (rand()%level) - level/2);
    }
}

static void make_sin(unsigned char* target, int count, int phase, double stretch) {
    for (int i = 0; i < count; i++ ) {
        target[i] = 115*sin( (0.1+stretch)*0.0001*(i+phase) ) - 127;
    }
}

static void make_const(unsigned char* target, int count, unsigned char val) {
    for (int i = 0; i < count; i ++ ) {
        target[i] = val;
    }
}

static void make_square(unsigned char* target, int count, unsigned period) {
    for (int i = 0; i < count; i ++ ) {
        target[i] = ( i / period ) & 1 ? 20: 235;
    }
}

int DummyHardware::read(unsigned char *data, size_t length) {

    switch(state) {
    case State_TX_One:
        memcpy(data, buffer, length);
        state = State_Init;
        break;
    case State_Tx_ADC:
        memcpy(data, buffer + (SAMPLE_BUFFER_SIZE * bufferTransmitCounter), length);
        if (++bufferTransmitCounter == SAMPLE_BUFFER_COUNT)
            state = State_Init;
        break;
    default:
        Q_ASSERT(state == State_TX_One);
    }
    return length;
}

int DummyHardware::get_manufacturer_string(wchar_t *string, size_t maxlen) {
    return mbstowcs(string, "mru", maxlen);
}

int DummyHardware::get_product_string(wchar_t *string, size_t maxlen) {
    return mbstowcs(string, "SampleScope Software Emulation", maxlen);
}


void DummyHardware::makeSignal(DeviceConstants::Channel_t ch, DeviceConstants::TestSignal_t ts) {

    switch(ts) {
    case DeviceConstants::TestSignal_Off:
        if (ch == DeviceConstants::ADC_ch1) {
            make_sin(buffer, SAMPLE_COUNT, 0, config.sampleDelay);
            make_noise(buffer, SAMPLE_COUNT, 20);
        }
        else if (ch == DeviceConstants::ADC_ch2) {
            //    make_sin(buffer, 256, 90);
            make_square(buffer, SAMPLE_COUNT, 20);
            make_noise(buffer, SAMPLE_COUNT, 20);
        }
        break;
    case DeviceConstants::TestSignal_Tri:
        for (int i = 0; i < SAMPLE_COUNT; i ++ ) {
            buffer[i] = i;
        }
        break;
    case DeviceConstants::TestSignal_Tri_2:
        for (int j = 0; j < SAMPLE_BUFFER_COUNT; j++ ) {
            for (int i = 0; i < SAMPLE_BUFFER_SIZE; i ++ ) {
                buffer[j*SAMPLE_BUFFER_SIZE + i] = i;
            }
        }
        break;
    case DeviceConstants::TestSignal_Mid:
        make_const(buffer, SAMPLE_COUNT, 0x80);
        break;

    case DeviceConstants::TestSignal_Zero:
        make_const(buffer, SAMPLE_COUNT, 0x00);
        break;
    }

}

int DummyHardware::write(const unsigned char *data, size_t length) {
    Q_ASSERT(state == State_Init);

#define ACK() { encoder->ack = data[1] + 1; }
#define NACK() { encoder->ack = 0xff; }

    DeviceConstants::opcode_decoder_t* decoder = (DeviceConstants::opcode_decoder_t*)&data[1];
    DeviceConstants::result_encoder_t* encoder = (DeviceConstants::result_encoder_t*)&buffer[0];

    switch(decoder->opcode) {

    case DeviceConstants::OP_PING:
        ACK();
        state = State_TX_One;
        break;

    case DeviceConstants::OP_SET_CONFIG:
        ACK();
        config = decoder->args.set_config_args;
        state = State_TX_One;
        break;

    case DeviceConstants::OP_GET_INFO:
    {
        DeviceConstants::device_info_t info;
        info.sizeInfo = sizeof(DeviceConstants::device_info_t);
        info.sizeConfig = sizeof(DeviceConstants::osci_config_t);
        info.bufferCount = SAMPLE_BUFFER_COUNT;
        info.bufferSize = SAMPLE_BUFFER_SIZE;
        info.version = 0;
        ACK();
        encoder->args.get_info_args = info;
        state = State_TX_One;
    }
    break;

    case DeviceConstants::OP_SAMPLE_SINGLE:
        switch (decoder->args.sample_single_args.inputChannel) {
        case DeviceConstants::ADC_triggerLevel:
            make_const(buffer, SAMPLE_COUNT, 255.0 * config.triggerLevel / 4096.0);
            make_noise(buffer, SAMPLE_COUNT, 10);
            break;

        case DeviceConstants::ADC_ch1:
        case DeviceConstants::ADC_ch2:

            makeSignal(decoder->args.sample_single_args.inputChannel, decoder->args.sample_single_args.testSignal);
            break;
        }
        ACK();
        bufferTransmitCounter = 0;
        state = State_Tx_ADC;

        break;
    case DeviceConstants::OP_SAMPLE_INTERLEAVED:
        makeSignal(DeviceConstants::ADC_ch1, decoder->args.sample_single_args.testSignal);
        ACK();
        bufferTransmitCounter = 0;
        state = State_Tx_ADC;
        break;

    default:
        NACK();
        Q_ASSERT( 1 == 0 );
    }
    return length;
}

bool DummyHardware::isOpen() {
    return state != State_Closed;
}

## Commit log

2012-05-01 random commit
    [Analog.sch, MCU.sch, gen.sch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]
2012-05-03 cleanup
    cleanup of layout/schematic
    minor changes to frontend
    [Analog.sch, MCU.sch, osci.brd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]
2012-05-06 fixed firmware issue; gui improvements; fft+xy-graph, rms and avg measurement
    [sample rates.ods, wavegen_amp.ods]
2012-05-06 fixed device hangup; gui improvements; interleaved sampling in asm; common (FE/BE) include file with definitions
    [HardwareProfile.h, SampleNoDelayInterleaved.asm, common.h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]
2012-05-07 all working fine; fully implemented ASM sampling routines; time scale calibrated; implemented graphAutoCorrelation; implemented first measurements + measurement guis
2012-05-09 implemented dummy device
2012-05-10 some renaming to 'SampleScope', aboutdialog, hardware selection, pcb cleanup
    [Analog.sch, MCU.sch, osci.brd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]
2012-05-11 added schematic pdfs
2012-05-16 simplified firmware, improved ui
    * removed "testsignal" opcodes, made it argument to sample opcode
    * removed tx states for multiple buffers
    * added further calibration for timebase
    * added zoom to plots
    * refactored measurements to separate class
    * refined frequency measurement by
    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
    [sample rates.ods]
2012-05-16 forgot debug code in firmware
    [sample rates.ods]
2012-05-16 ported to PIC18F4455, now 1024 samples
2012-05-17 doc update: schematics.pdf
    [Analog.sch, MCU.sch, osci.sch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]
2012-05-17 doc update: pcb.pdf
    [osci.brd]
2012-05-17 doc update: recreated schematics.pdf, was lost on last update
2012-05-18 pcb update: rename directory to 'pcb'; rename kicad project to 'SampleScope'
    [Analog.sch, MCU.sch, SampleScopePCB.brd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]
2012-05-19 remove ppm parts list
    [PPM1MHz Parts List.ods]
